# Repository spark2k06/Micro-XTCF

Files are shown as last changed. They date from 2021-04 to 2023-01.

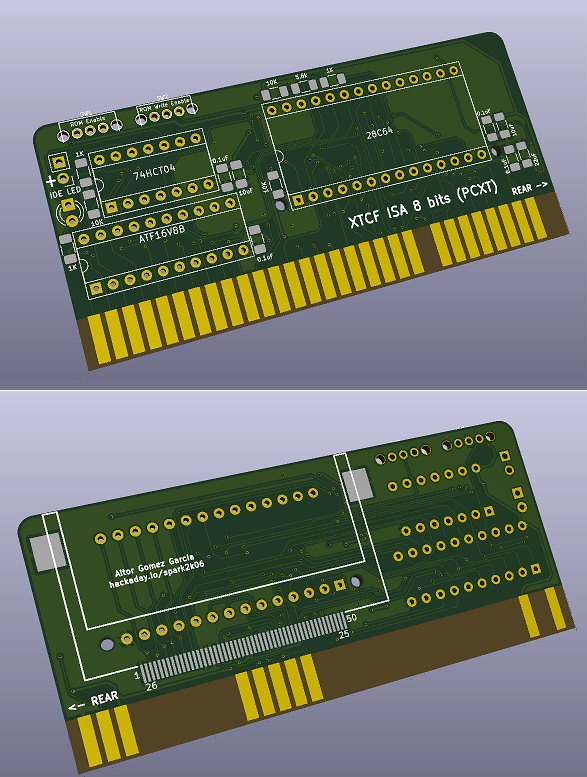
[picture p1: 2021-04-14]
render/Micro-XTCFv1_1.png

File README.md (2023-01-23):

Micro XTCF (Very Low Profile) Rev1.0 ReadMe
----------------------------

8-bit ISA CompactFlash interface + Boot ROM (two separate functions that can be used individually).

Credit:
-------

Design uses schematic from Monotech-PC, which, in turn, is based on the schematic from Sergey Kiselev:

https://github.com/monotech/monotech_xt-cf-mini
http://www.malinov.com/Home/sergeys-projects/xt-cf-lite

XT-IDE Universal BIOS\
www.xtideuniversalbios.org  
www.xtideuniversalbios.org/binaries  

Use the latest working binary that includes XTIDECFG.COM (config utility), ide_xt.bin (8086/8088), ide_xtp.bin (80186/V20/V30 and up).

More info:

https://www.tindie.com/products/spark2k06/micro-xtcf-isa-8-bits-very-low-profile/

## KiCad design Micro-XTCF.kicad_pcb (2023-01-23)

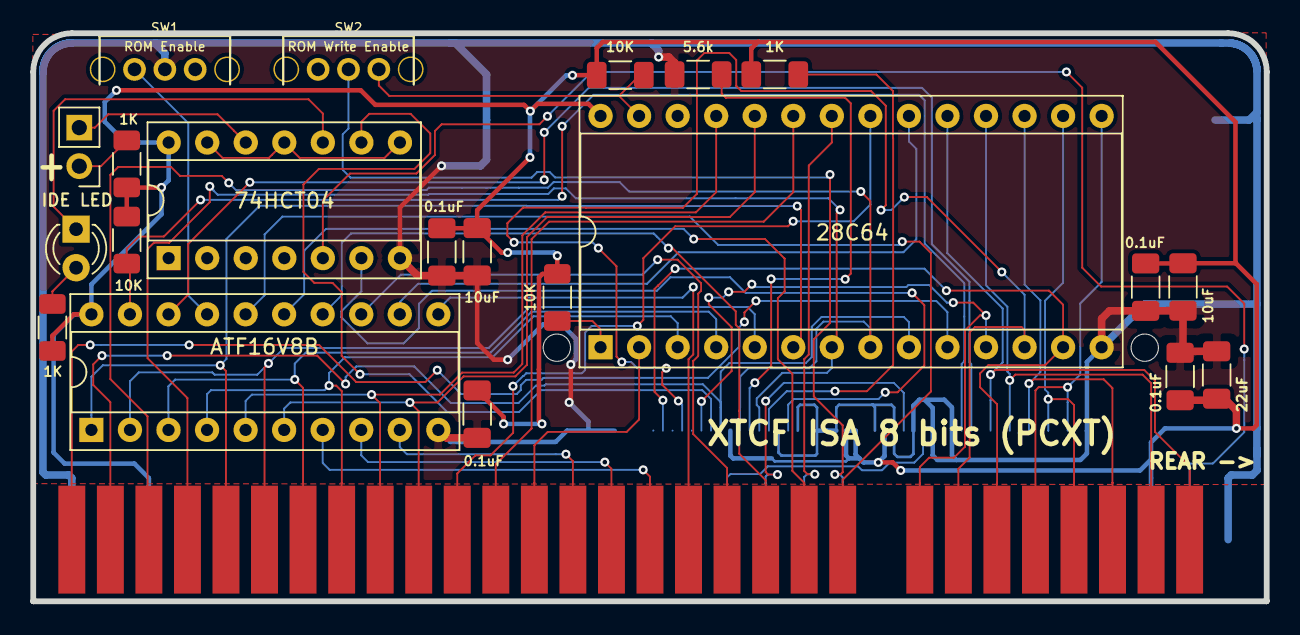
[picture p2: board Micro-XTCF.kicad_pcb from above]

Board: 2 copper layers, 81.3 x 37.4 mm, 23 parts (1 on the bottom side), 51 nets.

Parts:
BUS1: BUSPC_DEV; ISA-8BIT-XT-CF
C1, C2, C3, C7: 0.1uF; C_1206_3216Metric_Pad1.33x1.80mm_HandSolder
C4, C5: 10uF; C_1206_3216Metric_Pad1.33x1.80mm_HandSolder
C6: 22uF; C_1206_3216Metric_Pad1.33x1.80mm_HandSolder
D1: IDE LED; LED_D3.0mm
P1: CF_CARD; Custom_CF_Slot
P2: IDE LED; PinHeader_1x02_P2.54mm_Vertical
R1: 5.6k; R_1206_3216Metric_Pad1.30x1.75mm_HandSolder
R2, R3, R4: 1K; R_1206_3216Metric_Pad1.30x1.75mm_HandSolder
R5, R6, R7: 10K; R_1206_3216Metric_Pad1.30x1.75mm_HandSolder
SW1: ROM Enable; CKCOMP-OS102011MA1QN1
SW2: ROM Write Enable; CKCOMP-OS102011MA1QN1
U1: 28C64; DIP-28_W15.24mm_Socket
U2: ATF16V8B; DIP-20_W7.62mm_Socket
U5: 74HCT04; DIP-14_W7.62mm_Socket

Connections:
/A0: BUS1.62, U1.10
/A1: BUS1.61, P1.20, U1.9
/A2: BUS1.60, P1.19, U1.8
/A3: BUS1.59, P1.18, U1.7
/A4: BUS1.58, U1.6, U2.1
/A5: BUS1.57, U1.5, U2.2
/A6: BUS1.56, U1.4, U2.3
/A7: BUS1.55, U1.3, U2.4
/A8: BUS1.54, U1.25, U2.5
/A9: BUS1.53, U1.24, U2.6
/A10: BUS1.52, U1.21
/A11: BUS1.51, U1.23
/A12: BUS1.50, U1.2
/A13: BUS1.49, U2.9
/A14: BUS1.48, U2.8
/A15: BUS1.47, U2.7
/A16: BUS1.46, U2.11
/A17: BUS1.45, U2.13
/A18: BUS1.44, U2.14
/A19: BUS1.43, U2.15
/AEN: BUS1.42, U2.16
/CF_DMARQ: P1.43, R1.1
/CF_IORDY: P1.42, R4.2
/D0: BUS1.40, P1.21, U1.11
/D1: BUS1.39, P1.22, U1.12
/D2: BUS1.38, P1.23, U1.13
/D3: BUS1.37, P1.2, U1.15
/D4: BUS1.36, P1.3, U1.16
/D5: BUS1.35, P1.4, U1.17
/D6: BUS1.34, P1.5, U1.18
/D7: BUS1.33, P1.6, U1.19
/RDY/~BUSY: R6.1, U1.1
/RSTDRV: BUS1.2, U5.5
/~CF_CS0: P1.7, U2.18
/~CF_CS1: P1.32, R5.1, U2.19
/~CF_DASP: P1.45, U5.9
/~CF_RESET: P1.41, U5.6
/~IOR: BUS1.14, P1.34
/~IOW: BUS1.13, P1.35
/~MEMR: BUS1.12, U1.22
/~MEMW: BUS1.11, SW2.2
/~ROMW: R7.2, SW2.3, U1.27
/~ROM_CS: U1.20, U2.12
/~ROM_ENABLE: SW1.1, U2.17
GND: BUS1.1, BUS1.10, BUS1.31, C1.2, C2.2, C3.2, C4.2, C5.2, C6.2, C7.2, P1.1, P1.8, P1.9, P1.10, P1.11, P1.12, P1.14, P1.15, P1.16, P1.17, P1.39, P1.50, R1.2, SW1.2, U1.14, U2.10, U5.7
unnamed: D1.1, U5.10
unnamed: D1.2, R2.2
unnamed: P2.1, R3.2
unnamed: P2.2, U5.12
unnamed: U5.8, U5.11, U5.13
VCC: BUS1.3, BUS1.29, C1.1, C2.1, C3.1, C4.1, C5.1, C6.1, C7.1, P1.13, P1.36, P1.38, P1.44, R2.1, R3.1, R4.1, R5.2, R6.2, R7.1, U1.28, U2.20, U5.14

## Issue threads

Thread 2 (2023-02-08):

Can't boot when a CF card is installed on XTCF

A-Small-Mice, 2023-02-08:
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

I made my XTCF from the data given. It does actually work, unless a CF card is installed. I can see that the XTIDE BIOS is loaded normally when the CF card is not installed. However, if I install a CF card, the system BIOS does not work and the computer freezes. The LED is always lit.

I tried using the XTCF for IBM 5150 and XT clones, but the results were the same. I also tried various types of CF cards.

I don't know how to solve it. Can you help me?

spark2k06, 2023-02-08:
You need mirror type CF connectors, the ones that are placed on the opposite side to the rest of the components.

They are not easy to get, which is part of the reason why I have stopped selling them in favor of the new model I have called XTSD.

A-Small-Mice, 2023-02-08:
What is the mirror type CF connector? I compared my CF connectors with yours from the picture, but I can't find any difference.

A-Small-Mice, 2023-02-08:
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

I reversed the CF card and installed it. XT-IDE BIOS is loaded, the CF card is also found by the BIOS. But there is an error.

------

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
I wonder if this is the mirror type CF connector(板下) you mentioned.

spark2k06, 2023-02-08:
Exactly, the card has to look like this, with the mirror type connector, because the insertion rails are correct:

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

If your connector looks like this... it's no good, probably not even if you force it backwards:

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

spark2k06, 2023-02-08:
Anyway, in the XTIDE universal bios, make sure you choose XTCF instead of XTIDE rev1 or rev2.

A-Small-Mice, 2023-02-08:
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

Yeah! Finally! My XT-CF does work!

You corrected my two mistake.

* **Mistake 1** I have no mirror type CF card connector, so the CF card installed in the wrong direction. It caused system to freeze.
* **Mistake 2** I used XTIDE rev 1 as controller instead of XT-CF.

spark2k06, 2023-02-08:
Great! I'm glad it's working for you, I close the case.

Closed 2023-02-08.

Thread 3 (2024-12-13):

ROM window size

Leo-PL, 2024-12-13:
I see no discussions enabled, so I'm asking here:
Is the option ROM window size fixed at 8kB? I only see the window start address as variable.
I'm wondering if it could be extended by altering the SPLD image, as the ROM socket in theory can accept up to 64kB chips.

Which, makes it tempting to cram multiple option ROMs beside XTIDE universal BIOS - to avoid modding an XT board with  ROM size fixed at 8kB - into a single, bigger chip.

Thanks in advance for the reply.

Leo-PL, 2024-12-13:
After looking at the design, I'll reply to myself: HW design will need an alteration, some 28C64 pins have different functions than 27C128/256/512, and here only !ROMW could double as A14. A15 (here RDY/!BUSY) and A13 (N/C) would have to be bodge-wired in hardware.

spark2k06, 2024-12-13:
Sorry, but this PCB is not designed for more than 8Kb ROM size.

Closed 2024-12-13.

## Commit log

2021-04-14 Rev 1.1
    Added two decouple capacitors (100nF and 22uF) on the vcc line of the cf, some cf's requires a pump when they start, thanks @arananet for the suggestion.
    Added gerbers to the github project.
    [Micro-XTCF.sch]
2023-01-23 PCB layout sources added
    [Micro-XTCF.kicad_pcb, Micro-XTCF.kicad_sch]
